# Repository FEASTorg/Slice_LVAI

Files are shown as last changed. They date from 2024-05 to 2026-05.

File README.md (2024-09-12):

# Low-Voltage Analog Input Reader Slice

Low-Voltage Analog Input Reader Slice for BREAD.

## Introduction

[Short introduction on the project.]

## Usage

[Explain how to use the project. Include examples and screenshots if applicable.]

## Documentation 

Please refer to the [docs](/docs) for more info.

---

<div align="center">
  <p>
    
    
  </p>
</div>

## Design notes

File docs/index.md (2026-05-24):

---
title: "Slice LVAI Documentation"
description: "Overview and entry page for Slice LVAI project documentation."
nav_exclude: true
---

Welcome to the Slice LVAI project documentation.

## Board Renders

<figure style="display:inline-block; text-align:center; margin:10px;">
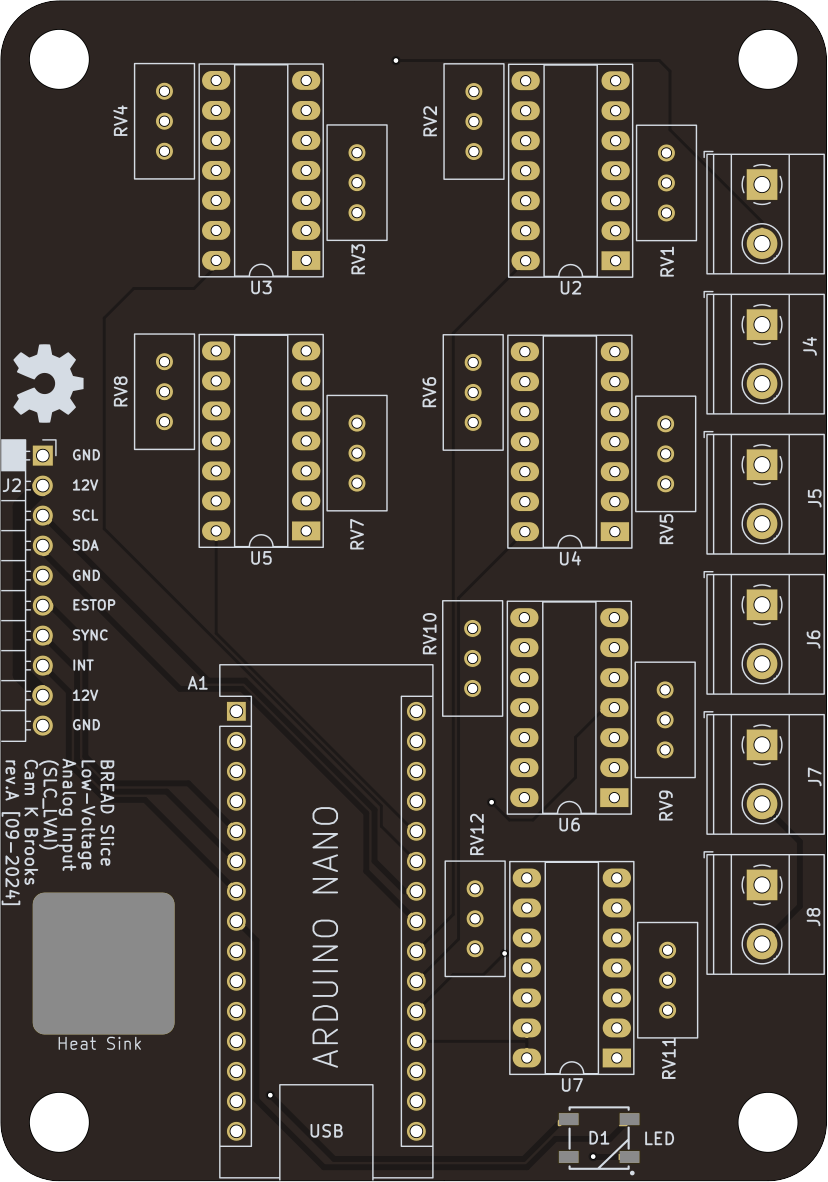
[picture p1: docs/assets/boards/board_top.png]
Board Top
  
  <figcaption>Top</figcaption>
</figure>

<figure style="display:inline-block; text-align:center; margin:10px;">
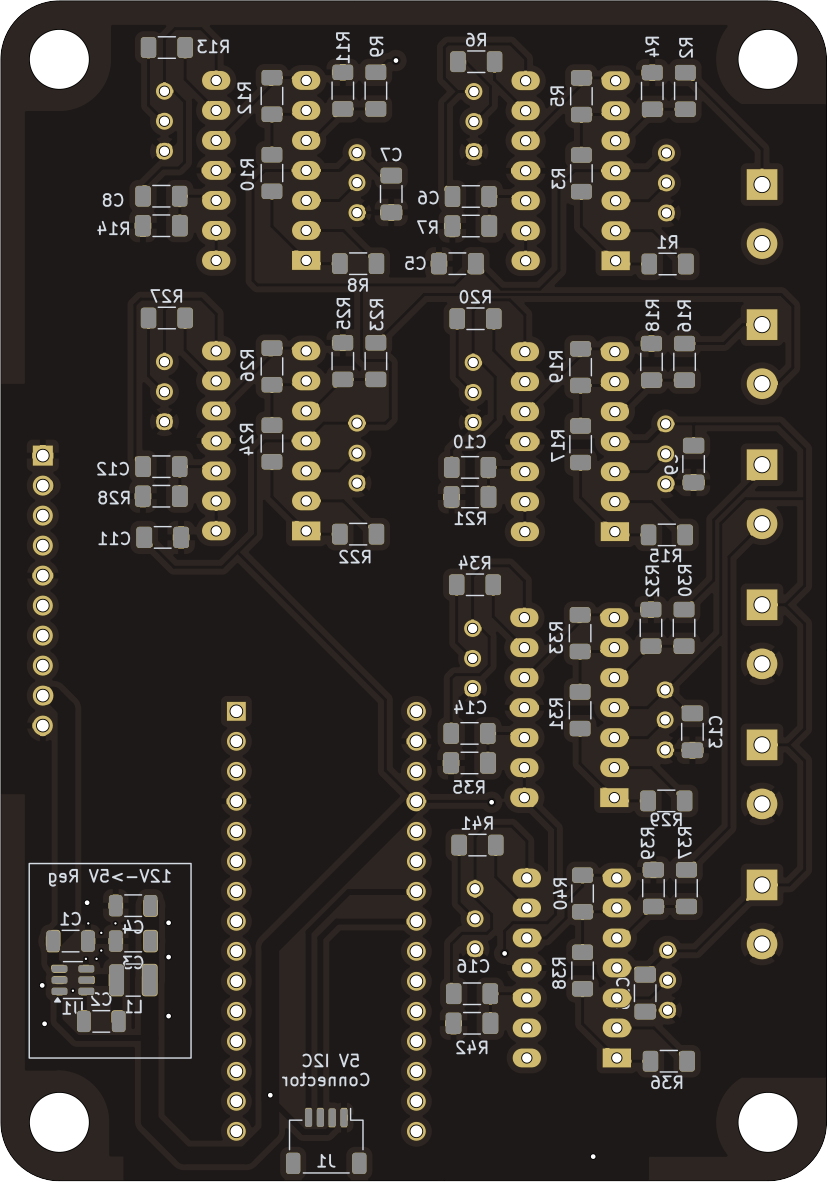
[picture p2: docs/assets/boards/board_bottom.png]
Board Bottom
  
  <figcaption>Bottom</figcaption>
</figure>

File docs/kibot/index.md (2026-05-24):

Slice LVAI KiBot Outputs
============================

Generated: 2026-05-24 at 16:14:21 UTC

## Artifacts

- [Schematic.pdf](./Schematic.pdf)
- [PCB.pdf](./PCB.pdf)
- [kibot.log](./kibot.log)
- [BREAD_Slice-bom.html](./BREAD_Slice-bom.html)
- [BREAD_Slice-ibom.html](./BREAD_Slice-ibom.html)

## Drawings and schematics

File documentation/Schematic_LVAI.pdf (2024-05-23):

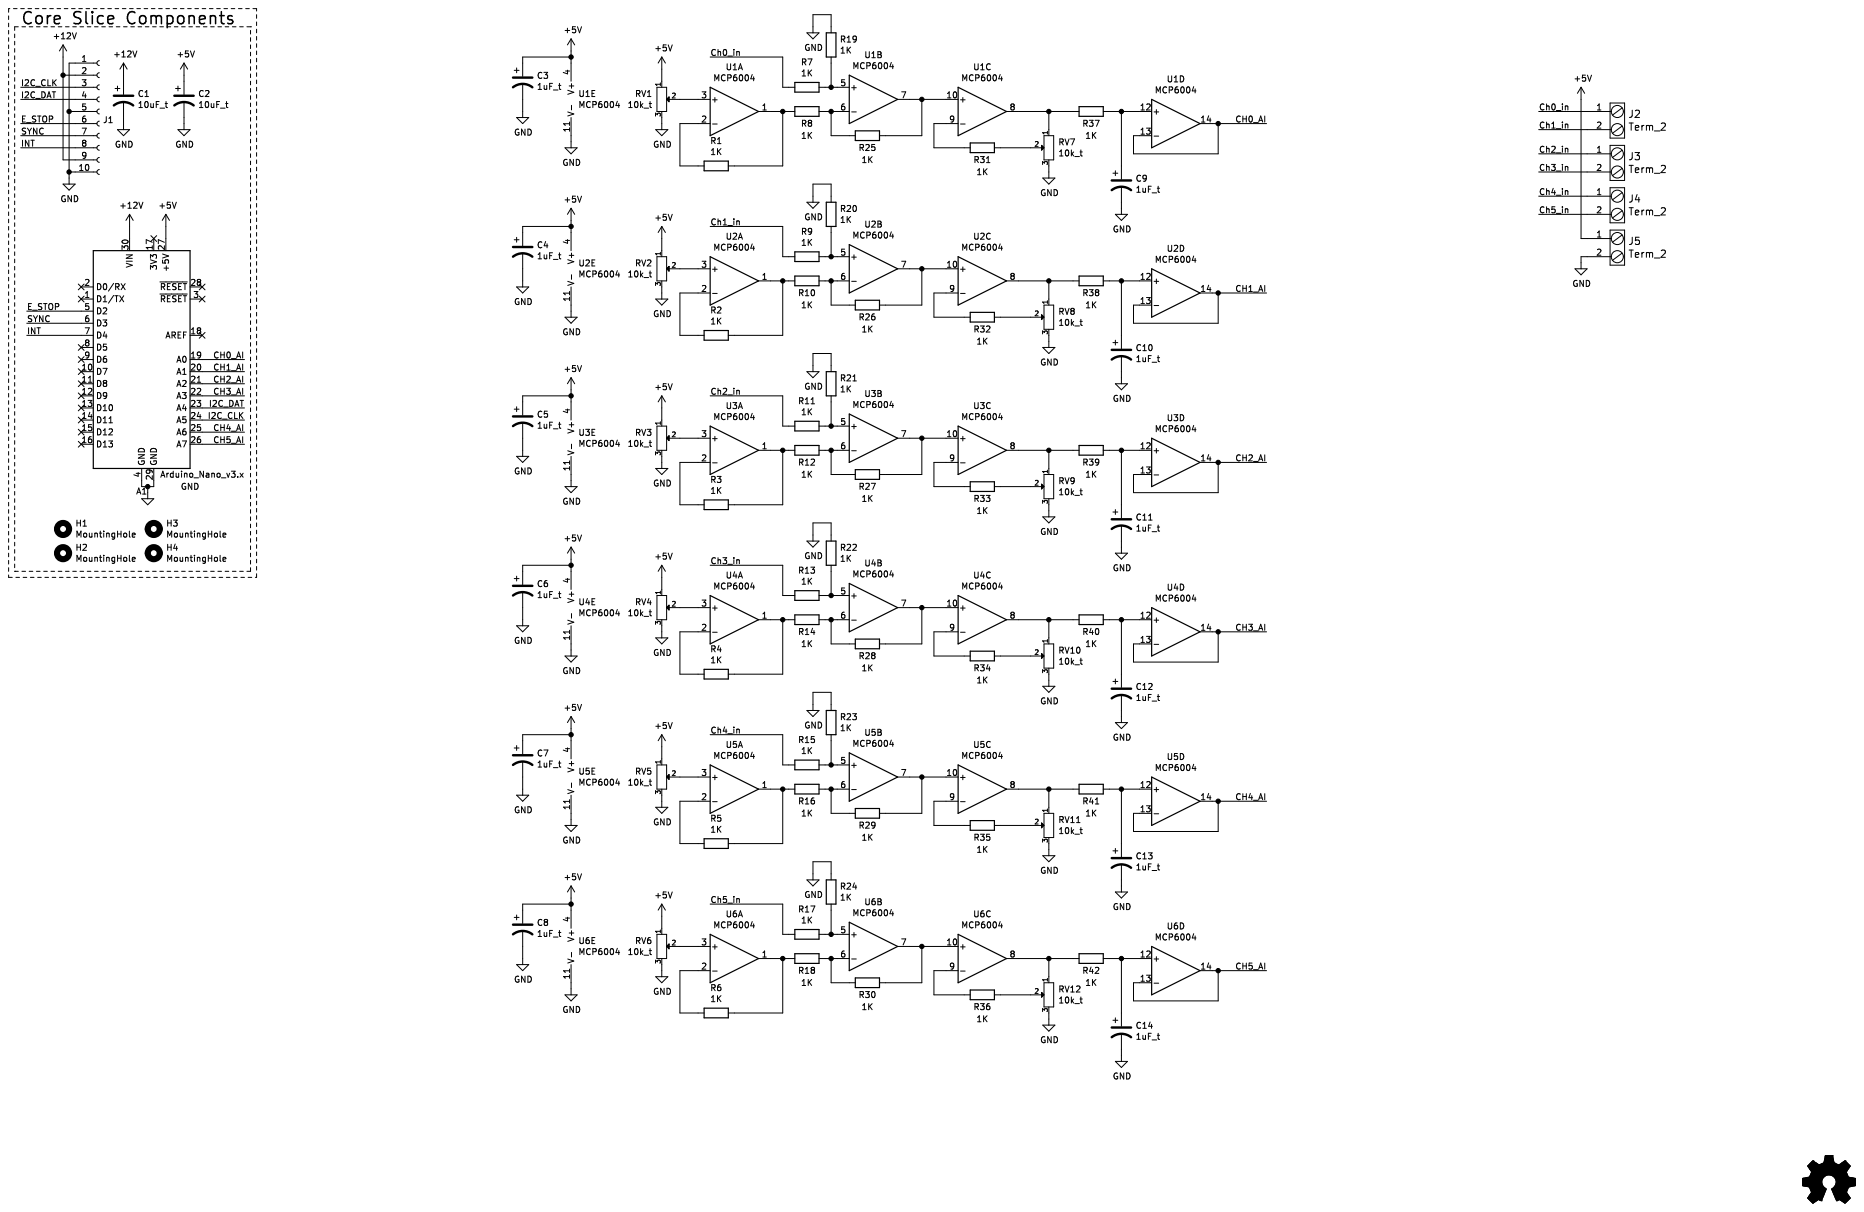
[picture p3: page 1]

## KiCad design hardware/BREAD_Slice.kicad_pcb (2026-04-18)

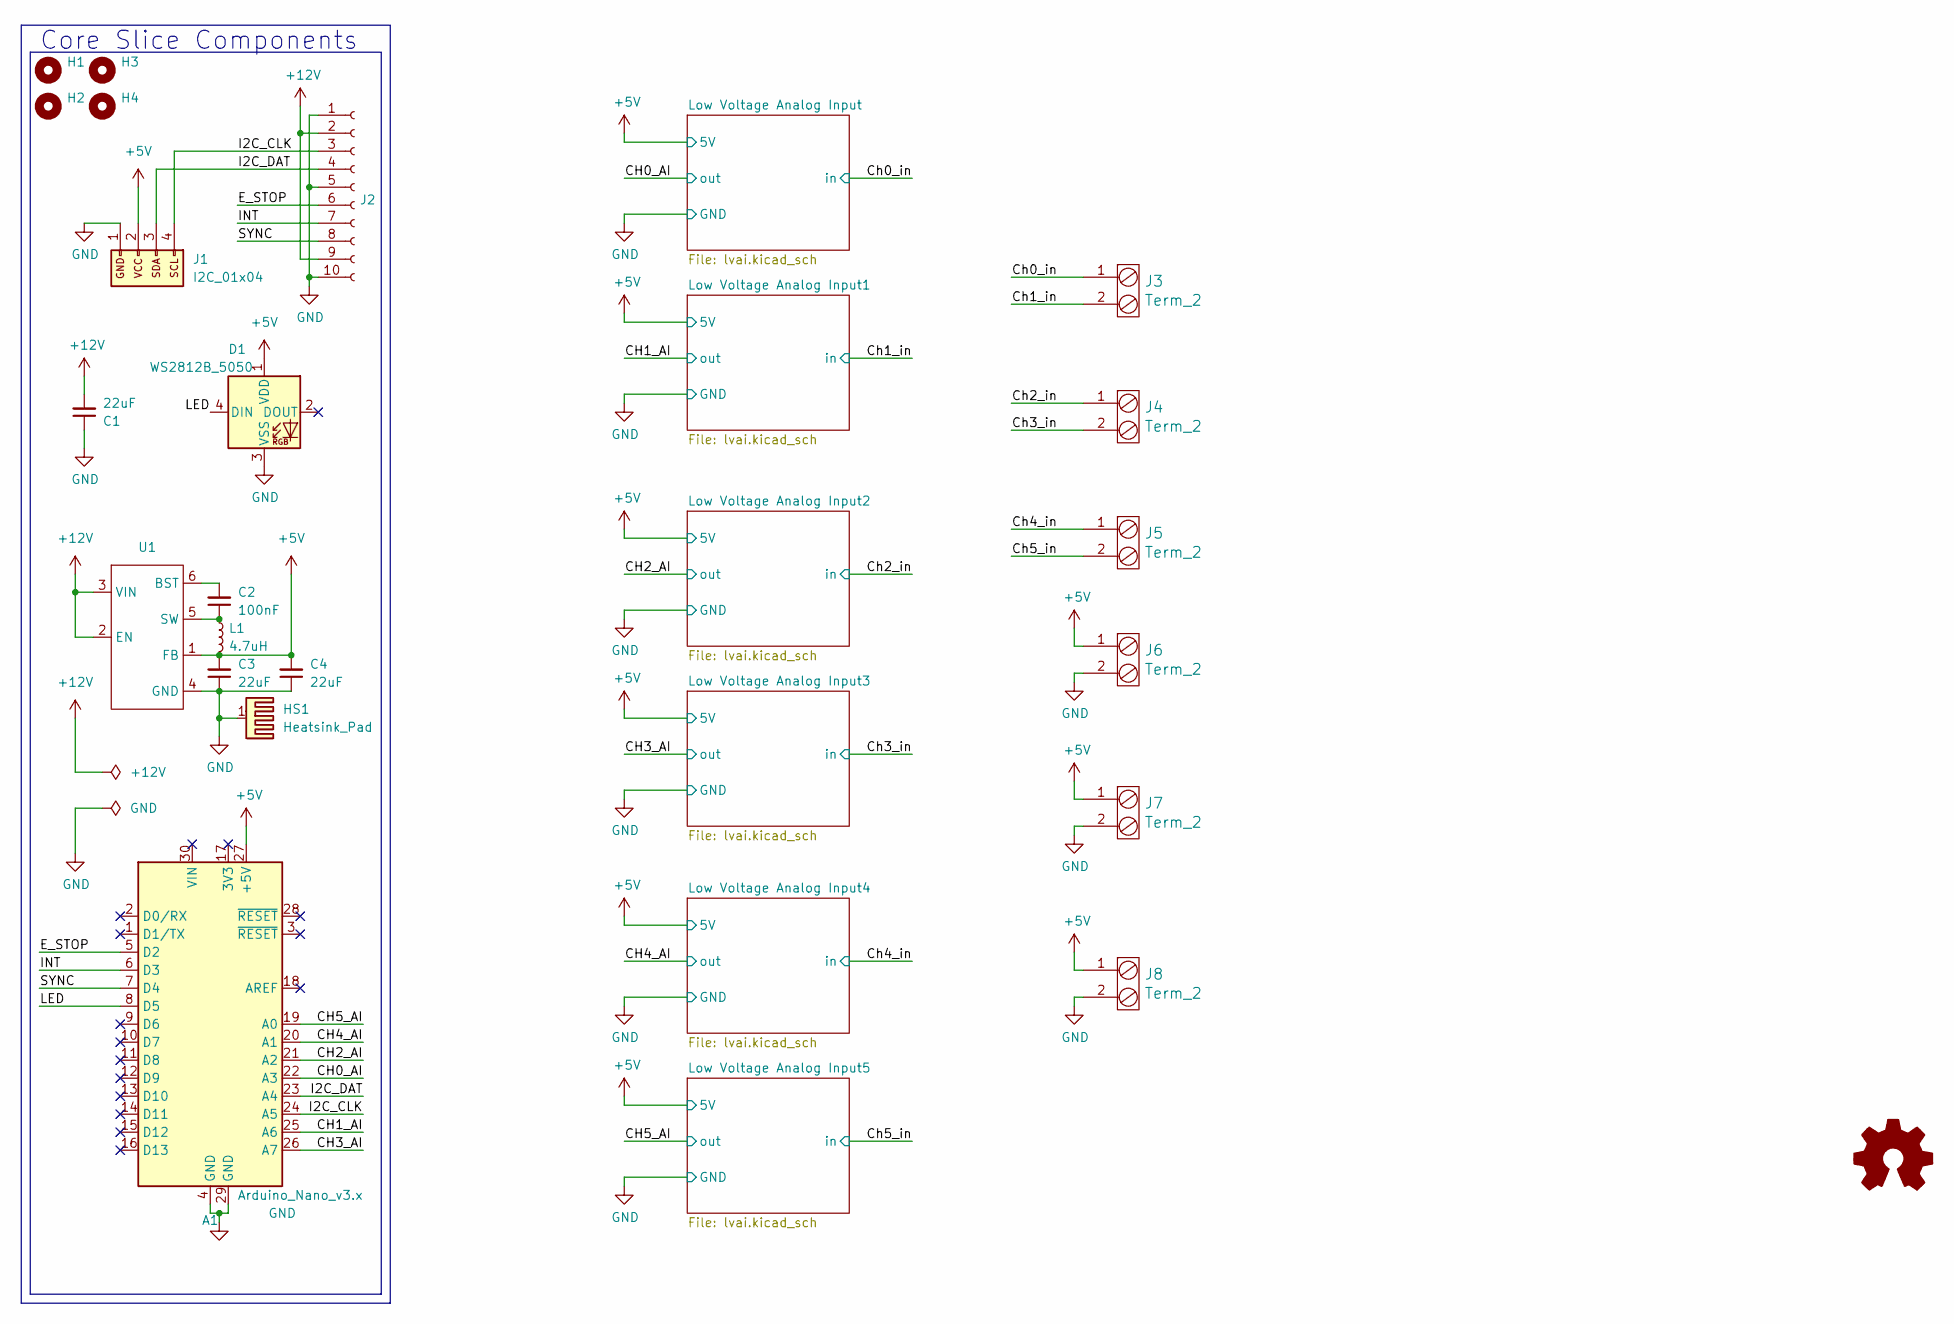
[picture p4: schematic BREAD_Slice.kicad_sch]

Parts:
A1: Arduino_Nano_v3.x; Arduino_Nano
C1, C3, C4: 22uF; C_1206_3216Metric
C2: 100nF; C_1206_3216Metric
D1: WS2812B_5050; WS2812-5050-4PIN
H1, H2, H3, H4: MountingHole; MountingHole_5mm
HS1: Heatsink_Pad; Thermal Pad
J1: I2C_01x04; JST_SH_SM04B-SRSS-TB_1x04-1MP_P1.00mm_Horizontal
J2: Conn_01x10_Female; PinSocket_1x10_P2.54mm_Horizontal
J3, J4, J5, J6, J7, J8: Term_2; TerminalBlock_Phoenix_MKDS-1,5-2_1x02_P5.00mm_Horizontal; Part # 1935161
L1: 4.7uH; L_1210_3225Metric
U1: TSOT-23-6

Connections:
+5V: A1.27 (+5V), C3.2, C4.2, D1.1 (VDD), J1.2, J6.1, J7.1, J8.1, L1.2, U1.1 (FB); also elsewhere on the board
+12V: C1.2, J2.2, J2.9, U1.2 (EN), U1.3 (VIN)
/CH0_AI: A1.22 (A3); also elsewhere on the board
/CH1_AI: A1.25 (A6); also elsewhere on the board
/CH2_AI: A1.21 (A2); also elsewhere on the board
/CH3_AI: A1.26 (A7); also elsewhere on the board
/CH4_AI: A1.20 (A1); also elsewhere on the board
/CH5_AI: A1.19 (A0); also elsewhere on the board
/Ch0_in: J3.1; also elsewhere on the board
/Ch1_in: J3.2; also elsewhere on the board
/Ch2_in: J4.1; also elsewhere on the board
/Ch3_in: J4.2; also elsewhere on the board
/Ch4_in: J5.1; also elsewhere on the board
/Ch5_in: J5.2; also elsewhere on the board
/E_STOP: A1.5 (D2), J2.6
/I2C_CLK: A1.24 (A5), J1.4, J2.3
/I2C_DAT: A1.23 (A4), J1.3, J2.4
/INT: A1.6 (D3), J2.7
/LED: A1.8 (D5), D1.4 (DIN)
/SYNC: A1.7 (D4), J2.8
GND: A1.4 (GND), A1.29 (GND), C1.1, C3.1, C4.1, D1.3 (VSS), HS1.1, J1.1, J2.1, J2.5, J2.10, J6.2, J7.2, J8.2, U1.4 (GND); also elsewhere on the board
unnamed: C2.2, U1.6 (BST)
unnamed: C2.1, L1.1, U1.5 (SW)

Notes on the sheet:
Core Slice Components

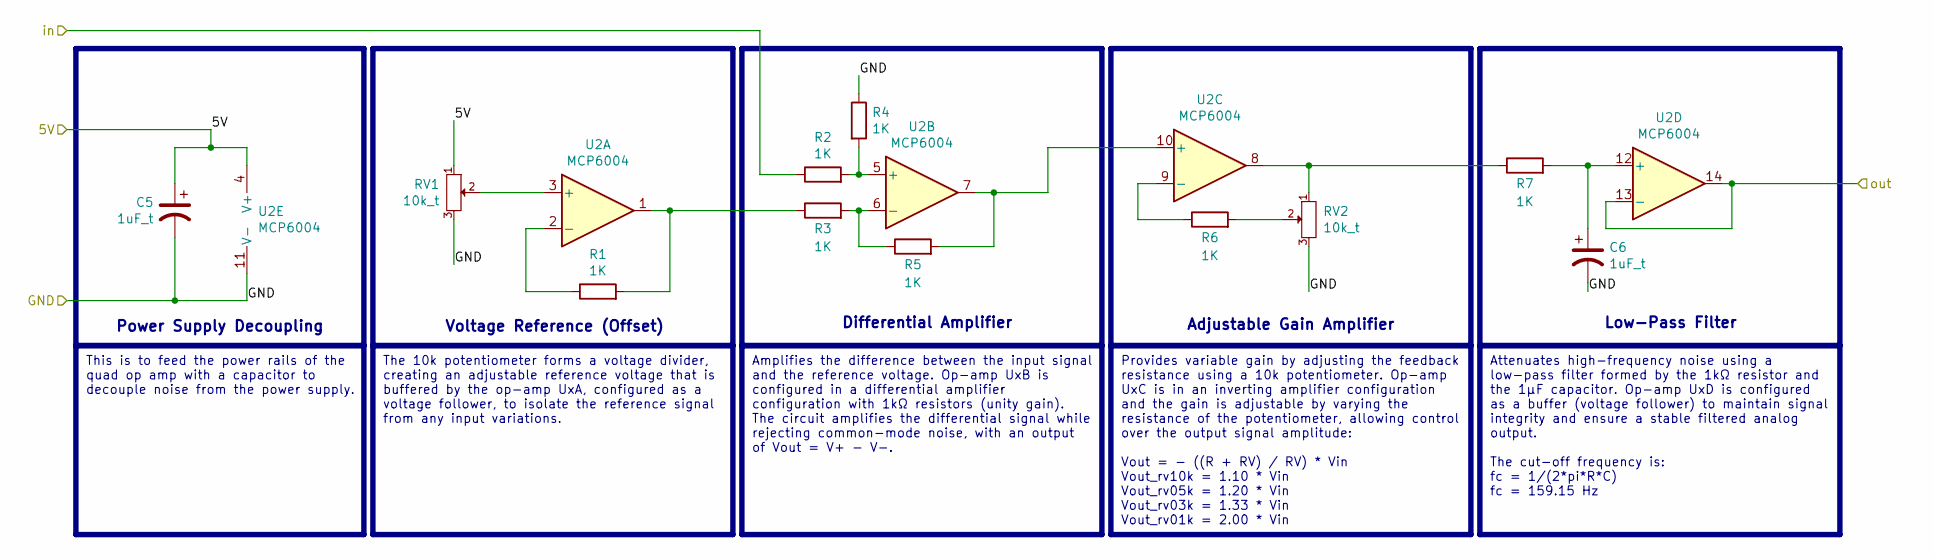
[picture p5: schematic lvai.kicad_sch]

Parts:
C5, C6: 1uF_t; C_1206_3216Metric_Pad1.33x1.80mm_HandSolder; Part # T491A105K025AT
R1, R2, R3, R4, R5, R6, R7: 1K; R_1206_3216Metric_Pad1.30x1.75mm_HandSolder; Part # RC1206FR-071KL
RV1, RV2: 10k_t; Potentiometer_Bourns_3296W_Vertical; Part # 1-1623849-0
U2: MCP6004; DIP-14_W7.62mm_Socket_LongPads

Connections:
+5V: C5.1, RV1.1, U2.4 (V+); also elsewhere on the board
/CH0_AI: U2.13 (-), U2.14; also elsewhere on the board
/Ch0_in: R2.1; also elsewhere on the board
GND: C5.2, C6.2, R4.1, RV1.3, RV2.3, U2.11 (V-); also elsewhere on the board
unnamed: R1.2, R3.1, U2.1
unnamed: R6.2, RV2.2
unnamed: R7.1, RV2.1, U2.8
unnamed: RV1.2, U2.3 (+)
unnamed: R1.1, U2.2 (-)
unnamed: R2.2, R4.2, U2.5 (+)
unnamed: R3.2, R5.1, U2.6 (-)
unnamed: R5.2, U2.7, U2.10 (+)
unnamed: R6.1, U2.9 (-)
unnamed: C6.1, R7.2, U2.12 (+)

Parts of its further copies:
C7, C8, C9, C10, C11, C12, C13, C14, C15, C16: 1uF_t; C_1206_3216Metric_Pad1.33x1.80mm_HandSolder; Part # T491A105K025AT
R8, R9, R10, R11, R12, R13, R14, R15, R16, R17, R18, R19, R20, R21, R22, R23, R24, R25, R26, R27, R28, R29, R30, R31, R32, R33, R34, R35, R36, R37, R38, R39, R40, R41, R42: 1K; R_1206_3216Metric_Pad1.30x1.75mm_HandSolder; Part # RC1206FR-071KL
RV3, RV4, RV5, RV6, RV7, RV8, RV9, RV10, RV11, RV12: 10k_t; Potentiometer_Bourns_3296W_Vertical; Part # 1-1623849-0
U3, U4, U5, U6, U7: MCP6004; DIP-14_W7.62mm_Socket_LongPads

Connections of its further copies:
+5V: C7.1, C9.1, C11.1, C13.1, C15.1, RV3.1, RV5.1, RV7.1, RV9.1, RV11.1, U3.4 (V+), U4.4 (V+), U5.4 (V+), U6.4 (V+), U7.4 (V+); also elsewhere on the board
/CH1_AI: U3.13 (-), U3.14; also elsewhere on the board
/CH2_AI: U4.13 (-), U4.14; also elsewhere on the board
/CH3_AI: U5.13 (-), U5.14; also elsewhere on the board
/CH4_AI: U6.13 (-), U6.14; also elsewhere on the board
/CH5_AI: U7.13 (-), U7.14; also elsewhere on the board
/Ch1_in: R9.1; also elsewhere on the board
/Ch2_in: R16.1; also elsewhere on the board
/Ch3_in: R23.1; also elsewhere on the board
/Ch4_in: R30.1; also elsewhere on the board
/Ch5_in: R37.1; also elsewhere on the board
GND: C7.2, C8.2, C9.2, C10.2, C11.2, C12.2, C13.2, C14.2, C15.2, C16.2, R11.1, R18.1, R25.1, R32.1, R39.1, RV3.3, RV4.3, RV5.3, RV6.3, RV7.3, RV8.3, RV9.3, RV10.3, RV11.3, RV12.3, U3.11 (V-), U4.11 (V-), U5.11 (V-), U6.11 (V-), U7.11 (V-); also elsewhere on the board
unnamed: R8.2, R10.1, U3.1
unnamed: R13.2, RV4.2
unnamed: R14.1, RV4.1, U3.8
unnamed: R15.2, R17.1, U4.1
unnamed: R20.2, RV6.2
unnamed: R21.1, RV6.1, U4.8
unnamed: R22.2, R24.1, U5.1
unnamed: R27.2, RV8.2
unnamed: R28.1, RV8.1, U5.8
unnamed: R29.2, R31.1, U6.1
unnamed: R34.2, RV10.2
unnamed: R35.1, RV10.1, U6.8
unnamed: R36.2, R38.1, U7.1
unnamed: R41.2, RV12.2
unnamed: R42.1, RV12.1, U7.8
unnamed: RV3.2, U3.3 (+)
unnamed: R8.1, U3.2 (-)
unnamed: R9.2, R11.2, U3.5 (+)
unnamed: R10.2, R12.1, U3.6 (-)
unnamed: R12.2, U3.7, U3.10 (+)
unnamed: R13.1, U3.9 (-)
unnamed: C8.1, R14.2, U3.12 (+)
unnamed: RV5.2, U4.3 (+)
unnamed: R15.1, U4.2 (-)
unnamed: R16.2, R18.2, U4.5 (+)
unnamed: R17.2, R19.1, U4.6 (-)
unnamed: R19.2, U4.7, U4.10 (+)
unnamed: R20.1, U4.9 (-)
unnamed: C10.1, R21.2, U4.12 (+)
unnamed: RV7.2, U5.3 (+)
unnamed: R22.1, U5.2 (-)
unnamed: R23.2, R25.2, U5.5 (+)
unnamed: R24.2, R26.1, U5.6 (-)
unnamed: R26.2, U5.7, U5.10 (+)
unnamed: R27.1, U5.9 (-)
unnamed: C12.1, R28.2, U5.12 (+)
unnamed: RV9.2, U6.3 (+)
unnamed: R29.1, U6.2 (-)
unnamed: R30.2, R32.2, U6.5 (+)
unnamed: R31.2, R33.1, U6.6 (-)
unnamed: R33.2, U6.7, U6.10 (+)
unnamed: R34.1, U6.9 (-)
unnamed: C14.1, R35.2, U6.12 (+)
unnamed: RV11.2, U7.3 (+)
unnamed: R36.1, U7.2 (-)
unnamed: R37.2, R39.2, U7.5 (+)
unnamed: R38.2, R40.1, U7.6 (-)
unnamed: R40.2, U7.7, U7.10 (+)
unnamed: R41.1, U7.9 (-)
unnamed: C16.1, R42.2, U7.12 (+)

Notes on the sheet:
Voltage Reference (Offset)
Differential Amplifier
Power Supply Decoupling
Low-Pass Filter
Adjustable Gain Amplifier
The 10k potentiometer forms a voltage divider, creating an adjustable reference voltage that is buffered by the op-amp UxA, configured as a voltage follower, to isolate the reference signal from any input variations.
Provides variable gain by adjusting the feedback resistance using a 10k potentiometer. Op-amp UxC is in an inverting amplifier configuration and the gain is adjustable by varying the resistance of the potentiometer, allowing control over the output signal amplitude: Vout = - ((R + RV) / RV) * Vin V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
This is to feed the power rails of the quad op amp with a capacitor to decouple noise from the power supply.
Attenuates high-frequency noise using a low-pass filter formed by the 1kΩ resistor and the 1μF capacitor. Op-amp UxD is configured as a buffer (voltage follower) to maintain signal integrity and ensure a stable filtered analog output. The cut-off frequency is: fc = 1/(2*pi*R*C) fc = 159.15 Hz
Amplifies the difference between the input signal and the reference voltage. Op-amp UxB is configured in a differential amplifier configuration with 1kΩ resistors (unity gain). The circuit amplifies the differential signal while rejecting common-mode noise, with an output of Vout = V+ - V-.

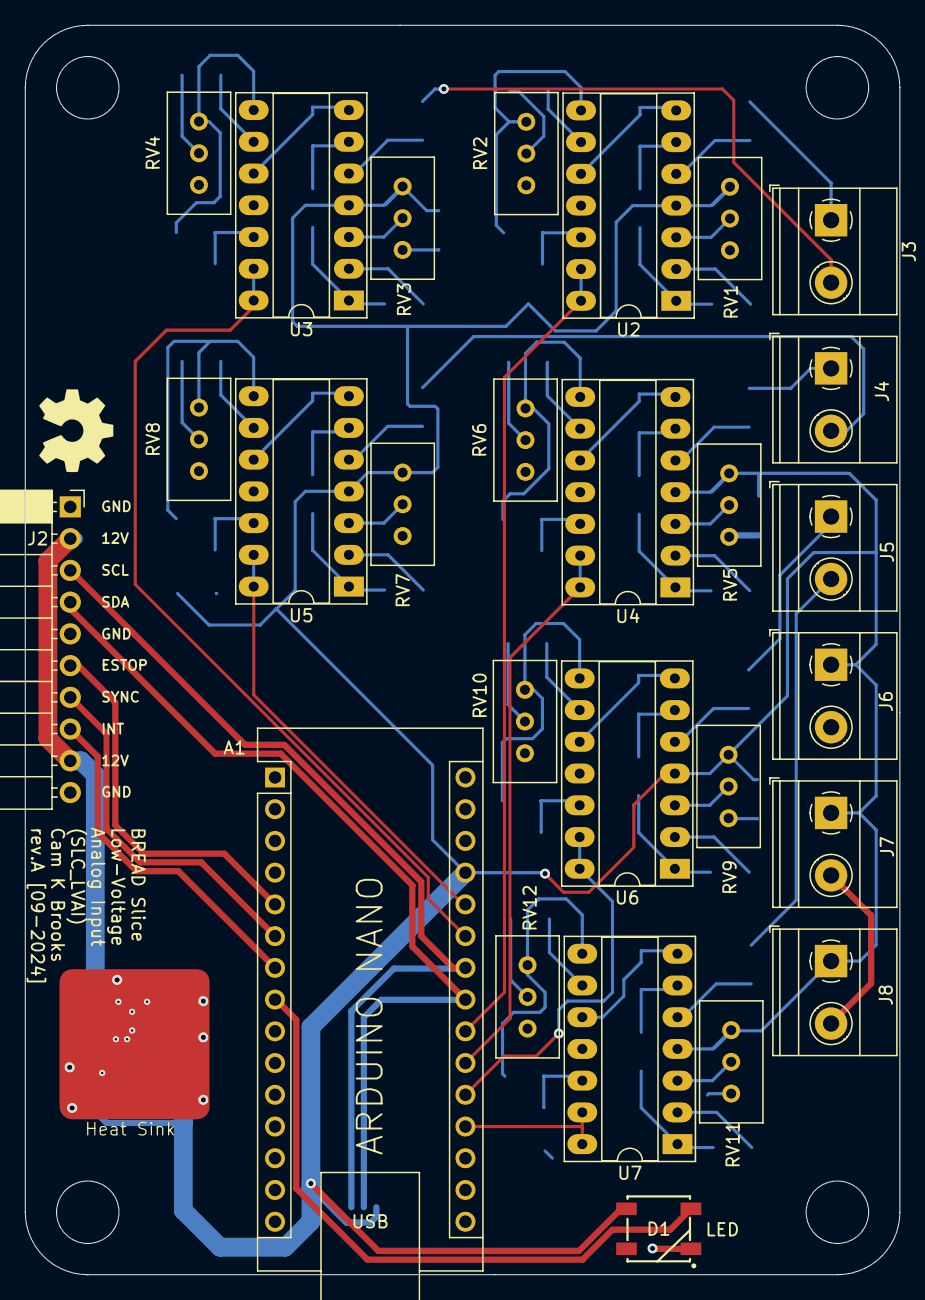
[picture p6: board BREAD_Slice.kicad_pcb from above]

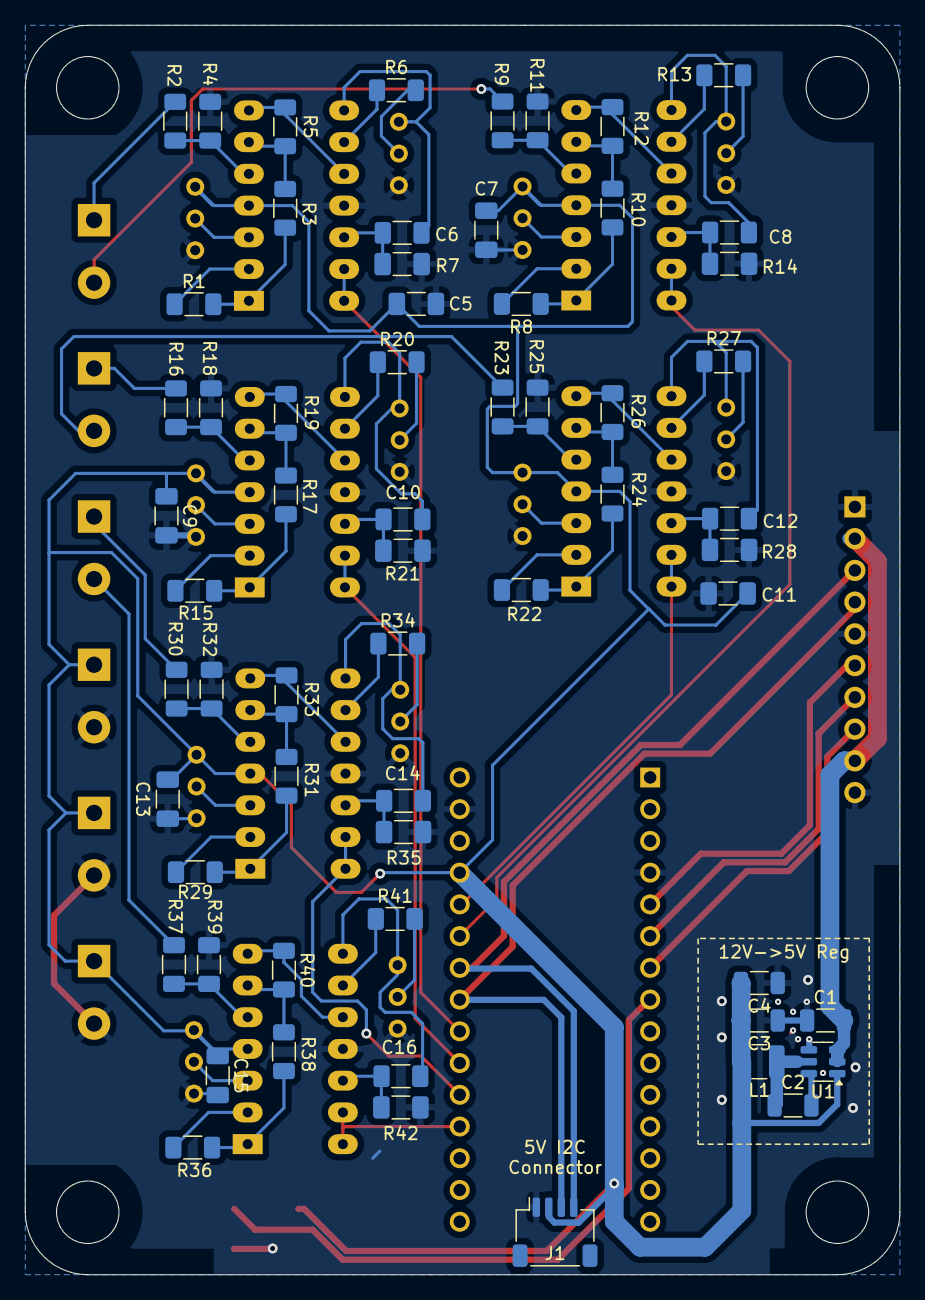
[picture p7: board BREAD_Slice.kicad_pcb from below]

Board: 2 copper layers, 70.0 x 100.0 mm, 94 parts (61 on the bottom side), 83 nets.

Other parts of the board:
Logo1: Logo_Open_Hardware_Small; OSHW-Symbol_6.7x6mm_SilkScreen

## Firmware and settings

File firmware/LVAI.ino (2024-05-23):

#include <Wire.h>
#include <SPI.h>
#include <arduinoFFT.h> //import the fft library
#define SAMPLES 64 //Must be a power of 2
#define SAMPLING_FREQUENCY 9600 //Hz (1k?) //Was 10000
arduinoFFT FFT = arduinoFFT(); // create FFT object
unsigned int sampling_period_us; unsigned long microseconds;
double vReal[SAMPLES]; //Real part of FFT array
double vImag[SAMPLES]; //Imaginary part of FFT array
double data;
int mode;

#define I2C_ADR 23 //Set this however you want

typedef union //Define a float that can be broken up and sent via I2C
{
 float number;
 uint8_t bytes[4];
} FLOATUNION_t;

// bunches of these
FLOATUNION_t RX_P1;
FLOATUNION_t RX_P2;
FLOATUNION_t RX_P3;
FLOATUNION_t RX_P4;
FLOATUNION_t RX_P5;
FLOATUNION_t RX_P6;

int Command, arg1, arg2, arg3, arg4, arg5, arg6;

// Class for defining and using analog channels
class Channel {
  private:
      byte pin;
      double samples[16];
  public:
      Channel(byte pin){
        this->pin = pin;
        init();
      }  
      int EN; 
      void init(){
        pinMode(pin, INPUT);
      }
      void sample(){
        if(EN){
          for(int i=0; i<16; i++){ //Arbitrarily choose an amount of samples up to 16
            samples[i] = analogRead(pin);
          }
        }
      }
      void disp(){
        if(EN){
          for(int i=0; i<16; i++){ //Print the same amount of samples
            Serial.println(samples[i]);
          }
        }
      }
      void freq(){
        for(int i=0; i<SAMPLES; i++){
          microseconds = micros();    //Overflows after around 70 minutes!
    
          vReal[i] = analogRead(pin); //Full Spectrum Line. We can do different segments later.
          vImag[i] = 0;
    
          while(micros() < (microseconds + sampling_period_us)){}
        }
        
        FFT.Windowing(vReal, SAMPLES, FFT_WIN_TYP_HAMMING, FFT_FORWARD);
        FFT.Compute(vReal, vImag, SAMPLES, FFT_FORWARD);
        FFT.ComplexToMagnitude(vReal, vImag, SAMPLES);
        double peak = FFT.MajorPeak(vReal, SAMPLES, SAMPLING_FREQUENCY);

        /*PRINT RESULTS*/
        Serial.println(peak); //Uncomment for Peak Frequency

        for(int i=2; i<(SAMPLES/2); i++)
        {
          /*View these three lines in serial terminal to see which frequencies have which amplitudes*/
          //Serial.print((i * 1.0 * SAMPLING_FREQUENCY) / SAMPLES, 1);
          //Serial.print(", ");
          //Serial.println(vReal[i], 1);    //View only this line in serial plotter to visualize the bins
        }
      }
};

Channel CH0(A0); 
Channel CH1(A1); 
Channel CH2(A2); 
Channel CH3(A3); 
Channel CH4(A6); 
Channel CH5(A7); 

String inputString = "";         // a String to hold incoming data
boolean stringComplete = false;  // whether the string is complete

void setup() {
  Wire.begin(I2C_ADR);            // join i2c bus with address #8
  //Wire.onReceive(receiveEvent);   // register event
  //Wire.onRequest(requestEvent);   // register event

  sampling_period_us = round(1000000*(1.0/SAMPLING_FREQUENCY));

  // Init all channels as not enabled
  
  CH0.EN = 1;
  CH1.EN = 0;
  CH2.EN = 0;
  CH3.EN = 0;
  CH4.EN = 0;
  CH5.EN = 0;
  
  inputString.reserve(50);

  Serial.begin(115200);

  while (!Serial) delay(1); // wait for Serial on Leonardo/Zero, etc
  delay(500);
}

void loop() {

  switch(mode){
    case 1: //Config
      break;
    case 2: //Time Domain
      if(CH0.EN){CH0.sample(); CH0.disp();}
      if(CH1.EN){CH1.sample(); CH1.disp();}
      if(CH2.EN){CH2.sample(); CH2.disp();}
      if(CH3.EN){CH3.sample(); CH3.disp();}
      if(CH4.EN){CH4.sample(); CH4.disp();}
      if(CH5.EN){CH5.sample(); CH5.disp();}
      break;
    case 3: //Freq Domain
      if(CH0.EN){CH0.freq();}
      if(CH1.EN){CH1.freq();}
      if(CH2.EN){CH2.freq();}
      if(CH3.EN){CH3.freq();}
      if(CH4.EN){CH4.freq();}
      if(CH5.EN){CH5.freq();}
      break;
    default://None
      break;
  }
  if (stringComplete) {
    // clear the string:
    inputString = "";
    stringComplete = false;
  }
}


void serialEvent() {
  while (Serial.available()) {
    // get the new byte:
    char inChar = (char)Serial.read();
    // add it to the inputString:
    inputString += inChar;
    // if the incoming character is a newline, set a flag so the main loop can
    // do something about it:
    if (inChar == '\n') {
      stringComplete = true;


      int result = sscanf(inputString.c_str(), "%d,%d,%d,%d,%d,%d,%d", &Command, &arg1, &arg2, &arg3, &arg4, &arg5, &arg6);

      Serial.print(Command);
      Serial.print(", ");
      Serial.print(arg1);
      Serial.print(", ");
      Serial.print(arg2);
      Serial.print(", ");
      Serial.print(arg3);
      Serial.print(", ");
      Serial.print(arg4);
      Serial.print(", ");
      Serial.print(arg5);
      Serial.print(", ");
      Serial.println(arg6);

      switch(Command){
        case 0:
          //standard comms configuration command
          break;

        case 1:
          
          CH0.EN = arg1;
          CH1.EN = arg2;
          CH2.EN = arg3;
          CH3.EN = arg4;
          CH4.EN = arg5;
          CH5.EN = arg6;
          
          break;
          
        case 2:
          mode = arg1;
      }
      
    }
  }
}

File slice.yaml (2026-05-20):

schema_version: "1.0"

# ── Identity ──────────────────────────────────────────────────────────────────
id: "slice-lvai"
name: "Low-Voltage Analog Input Reader"
status: "prototype"
category: "sensing"

summary: "6-channel low-voltage analog input reader with FFT analysis."
description: null

# ── Versioning ────────────────────────────────────────────────────────────────
version:
  hardware: "0.1.0"
  firmware: "0.1.0"
  manifest: "0.1.0"

# ── Compatibility ─────────────────────────────────────────────────────────────
compatibility:
  slice_spec: ">=0.1.0 <0.2.0"
  crumbs_protocol: null
  anolis_provider_api: null

# ── Hardware ──────────────────────────────────────────────────────────────────
hardware:
  mcu:
    type: "dev-board-socket"
    form_factor: "nano"
    primary: "ATmega328P"
    supported:
      - "ATmega328P"
  primary_ic: null
  hw_gen_current: 1
  hw_gen_supported: [1]
  pcb:
    layers: 2
    thickness: "1.6mm"
    copper_weight: "1oz"
    dimensions: "70mm x 100mm"
  connectors:
    - ref: "J1"
      type: "slice-bus-10pin"
      purpose: "power-and-i2c"
  mounting:
    pattern: "slice-standard-v0"
    hole_size: "M3"
    inset: "5mm"
  pcb_color_prototype: null
  pcb_color_production: null
  enclosure:
    supported: false
    path: null

# ── Electrical ────────────────────────────────────────────────────────────────
electrical:
  input_voltage: "12V"
  logic_voltage: "5V"
  max_current: null
  protection: null
  isolation: null

# ── Interfaces ────────────────────────────────────────────────────────────────
interfaces:
  host:
    type: "i2c"
    address_default: 23
    address_configurable: false
  data:
    inputs:
      - name: "CH1"
        type: "analog-voltage"
      - name: "CH2"
        type: "analog-voltage"
      - name: "CH3"
        type: "analog-voltage"
      - name: "CH4"
        type: "analog-voltage"
      - name: "CH5"
        type: "analog-voltage"
      - name: "CH6"
        type: "analog-voltage"
    outputs: []

# ── Capabilities ──────────────────────────────────────────────────────────────
capabilities:
  - id: "analog_input"
    channels: 6
    control_modes:
      - "sample"
      - "fft"

# ── Firmware ──────────────────────────────────────────────────────────────────
firmware:
  language: "C++"
  framework: "arduino"
  build_system: "arduino-ide"
  entry_point: "firmware/LVAI.ino"
  path: "firmware"
  required: false
  targets:
    - "nano"
  lib_deps:
    - "arduinoFFT"
  i2c:
    address_default: 23
    address_configurable: false
  libraries:
    - name: "Wire"
      purpose: "I2C communication"
    - name: "SPI"
      purpose: "SPI bus"
    - name: "arduinoFFT"
      purpose: "FFT frequency analysis"

# ── Protocol ──────────────────────────────────────────────────────────────────
protocol:
  type: "i2c-register"
  description: "I2C slave at address 23; receives commands and returns float data via union encoding."
  commands: []

# ── Software ──────────────────────────────────────────────────────────────────
software: null

# ── Artifacts ─────────────────────────────────────────────────────────────────
artifacts:
  schematic: "hardware/BREAD_Slice.kicad_sch"
  pcb: "hardware/BREAD_Slice.kicad_pcb"
  firmware: "firmware/LVAI.ino"
  docs: null
  bom: "documentation/BOM_TEMP.ods"
  gerbers: "hardware/Gerbers.zip"
  pick_and_place: null
  datasheets: []

# ── Manufacturing ─────────────────────────────────────────────────────────────
manufacturing: null

# ── Validation ────────────────────────────────────────────────────────────────
validation: null

# ── Safety ────────────────────────────────────────────────────────────────────
safety: null

# ── Dependencies ──────────────────────────────────────────────────────────────
dependencies: null

# ── Relations ─────────────────────────────────────────────────────────────────
related: null

# ── Maintainers ───────────────────────────────────────────────────────────────
maintainers:
  - name: "Cameron Brooks"
    role: "owner"

# ── License ───────────────────────────────────────────────────────────────────
license:
  hardware: "CERN-OHL-S-2.0"
  firmware: "GPL-3.0-only"
  software: null
  docs: "CC-BY-4.0"

# ── Repository ────────────────────────────────────────────────────────────────
repository:
  url: "https://github.com/feastorg/Slice_LVAI"

# ── Metadata ──────────────────────────────────────────────────────────────────
metadata:
  created: "2026-05-19"
  updated: "2026-05-19"
  tags:
    - "analog-input"
    - "fft"
    - "voltage-measurement"
    - "signal-processing"

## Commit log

2024-09-12 extensive documentation, remade board, subcircuits for all
    [BREAD_Slice-B_Cu.gbr, BREAD_Slice-B_Mask.gbr, BREAD_Slice-B_Paste.gbr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]
2024-09-30 JLCPCB order rev-A
    [BREAD_Slice-B_Cu.gbr, BREAD_Slice-B_Mask.gbr, BREAD_Slice-B_Paste.gbr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]
2026-04-18 chore: minor updates
    [BREAD_Slice.kicad_pcb, BREAD_Slice.kicad_sch, lvai.kicad_sch]
2026-05-24 📄 KiBot index + board renders (auto)
